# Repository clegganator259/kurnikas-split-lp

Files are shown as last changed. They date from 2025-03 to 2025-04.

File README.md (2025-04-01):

# kurnikas-split-lp
My attempt at designing my perfect split ergo keyboard

# Attribution

For the battery connector and led footprints @celolides fantastic [footprint library](https://github.com/ceoloide/ergogen-footprints)
For the choc v1 reversible footprints @ergogen + @infused-kim, @ceoloide, @grazfather, @nxtk improvements

For the videos that helped make this possible [Christian Sellig's wonderful video](https://www.youtube.com/watch?v=7UXsD7nSfDY)
# BOM
## PCB Components
|Component | Quantity|
|---|---:|
|kurnikas-split-lp PCB | 2|
|Nice nano v2 compatible board | 2|
|Choc v1 Key switches | 64|
|SK6812 mini-e RGB | 64|
|EC12/EC11 low profile encoder | 2|
|1N4148W SOD123 Diodes | 64/66 if using EC11 Encoder|
|JST PH2 board connector | 2|
|3.7v Lipo battery thickness < 8mm | 2|
|JST PH2 male connectors for batteries| 2|
|7 pin on/off toggle slide switch | 2|
|SKQGABE010 touch switch smd | 2|

## Case components
### Full case
|Component | Quantity|
|---|---:|
|8mm m2 standoffs  | 10|
|m2 flat top screws| 10|
|[Left hand faceplate](production/full-case-3dprint/face-plate-left.stl)| 1|
|[Right hand faceplate](production/full-case-3dprint/face-plate-right.stl)| 1|
|[Left hand Backplate](production/full-case-3dprint/base-plate-right.stl)| 1|
|[Right hand Backplate](production/full-case-3dprint/base-plate-left.stl)| 1|

### Sandwich Case
|Component | Quantity|
|---|---:|
|m2x4mm chicago screws with max 3mm OD | 10|
|Faceplate ([laser cut](production/sandwich-case-laser-cut/faceplate.dxf)/[3d printed](production/sandwich-case-3dprint/faceplate.stl)) |2|
|Baseplate ([laser cut](production/sandwich-case-laser-cut/baseplate.dxf)/[3d printed](production/sandwich-case-3dprint/baseplate.stl)) |2|

## Making your own

For a more detailed tutorial please go to [the build tutorial](docs/tutorial.md)

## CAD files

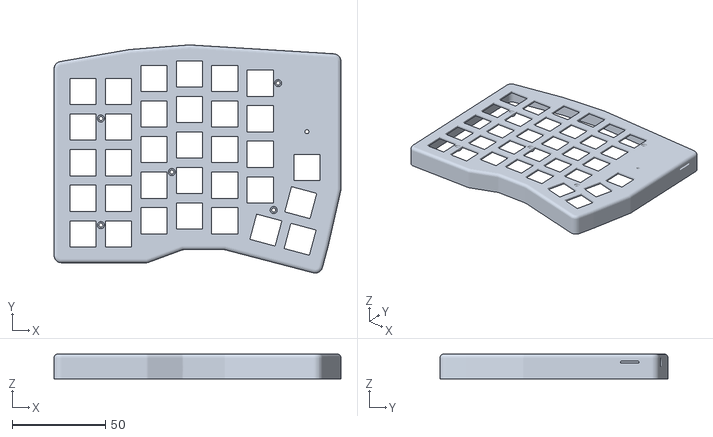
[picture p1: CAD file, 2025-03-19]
production/full-case-3dprint/face-plate-left.stl
153.8 x 122.3 x 13.3

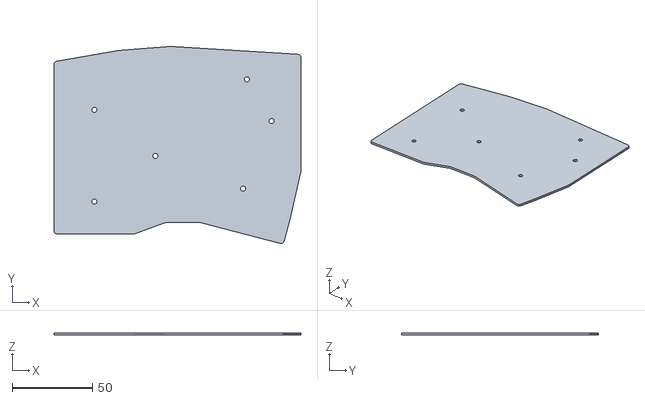
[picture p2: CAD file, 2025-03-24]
production/sandwich-case-3dprint/baseplate.stl
153.8 x 122.7 x 1.50

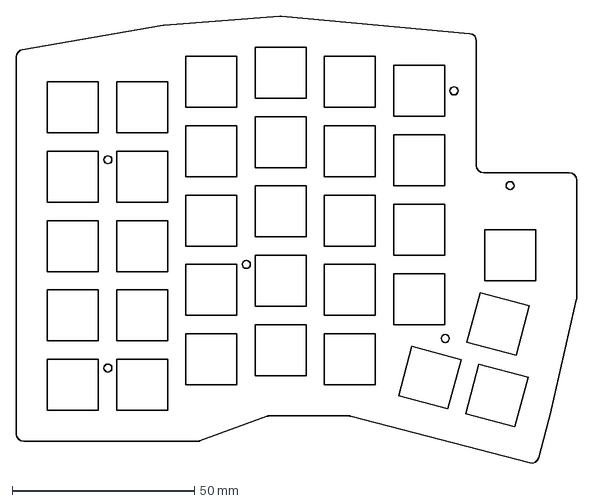
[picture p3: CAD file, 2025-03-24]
production/sandwich-case-laser-cut/faceplate.dxf
153.8 x 122.9 mm

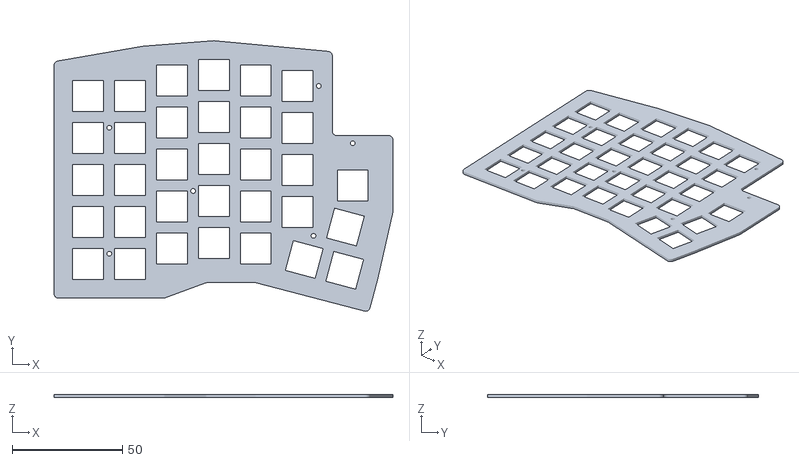
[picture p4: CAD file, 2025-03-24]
production/sandwich-case-3dprint/faceplate.stl
153.8 x 122.7 x 1.50

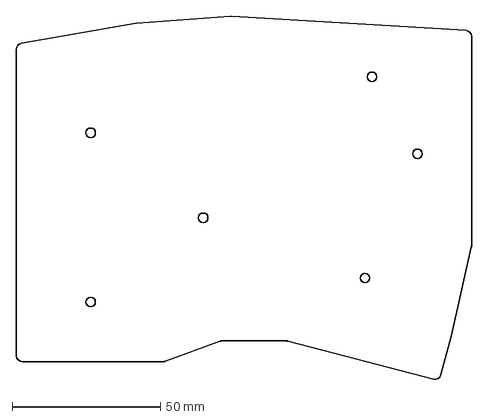
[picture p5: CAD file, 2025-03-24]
production/sandwich-case-laser-cut/baseplate.dxf
153.8 x 122.9 mm

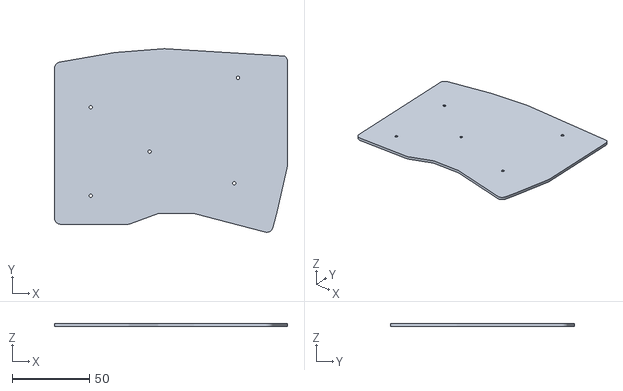
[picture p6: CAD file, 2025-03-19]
production/full-case-3dprint/base-plate-left.stl
150.3 x 118.5 x 2.00

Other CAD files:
production/full-case-3dprint/face-plate-right.stl
production/full-case-3dprint/base-plate-right.stl

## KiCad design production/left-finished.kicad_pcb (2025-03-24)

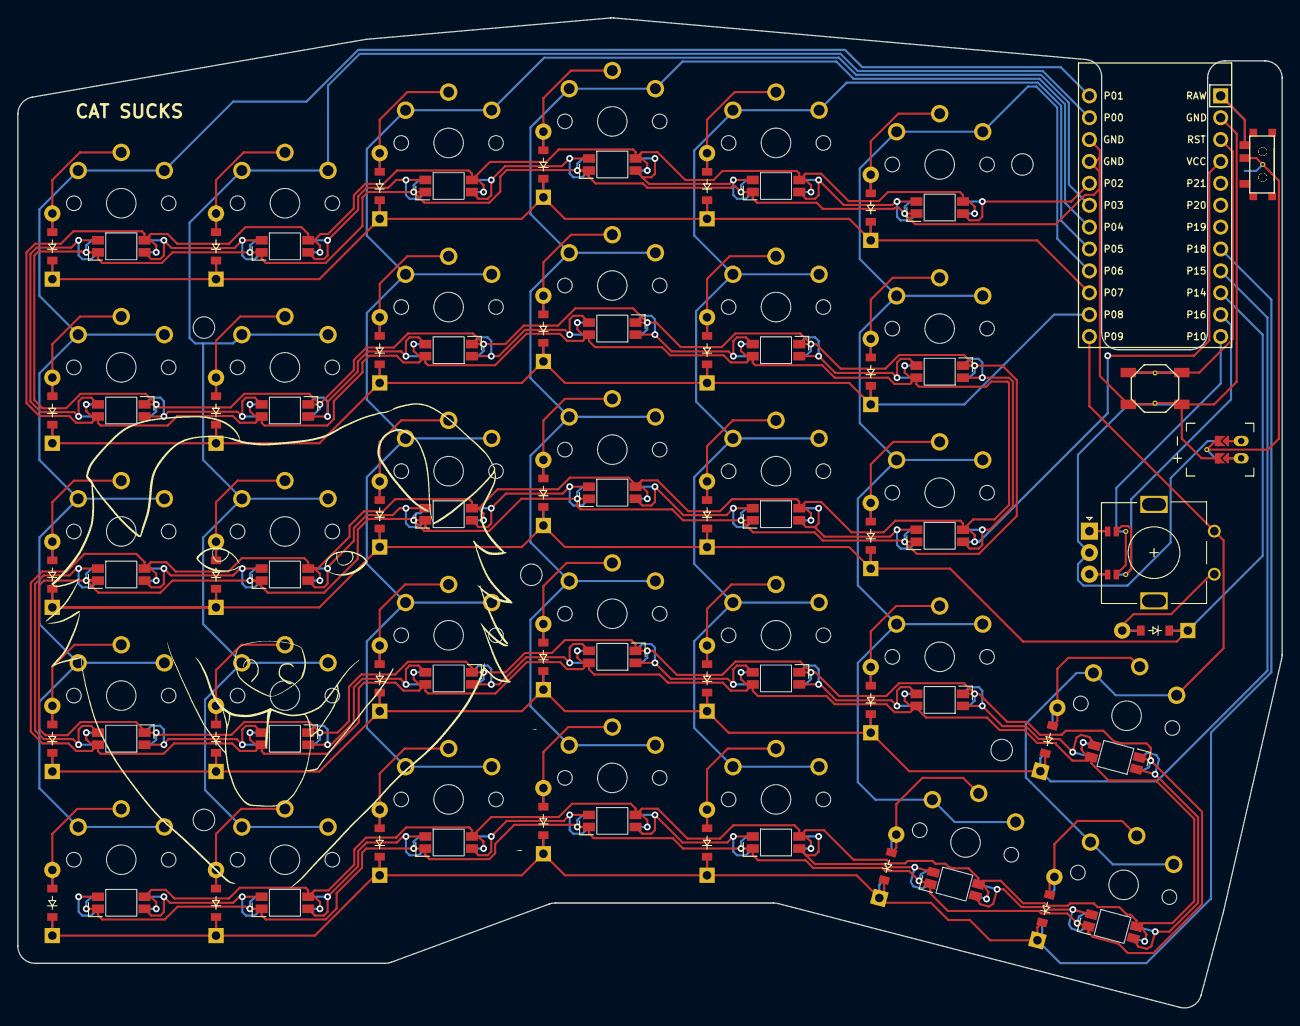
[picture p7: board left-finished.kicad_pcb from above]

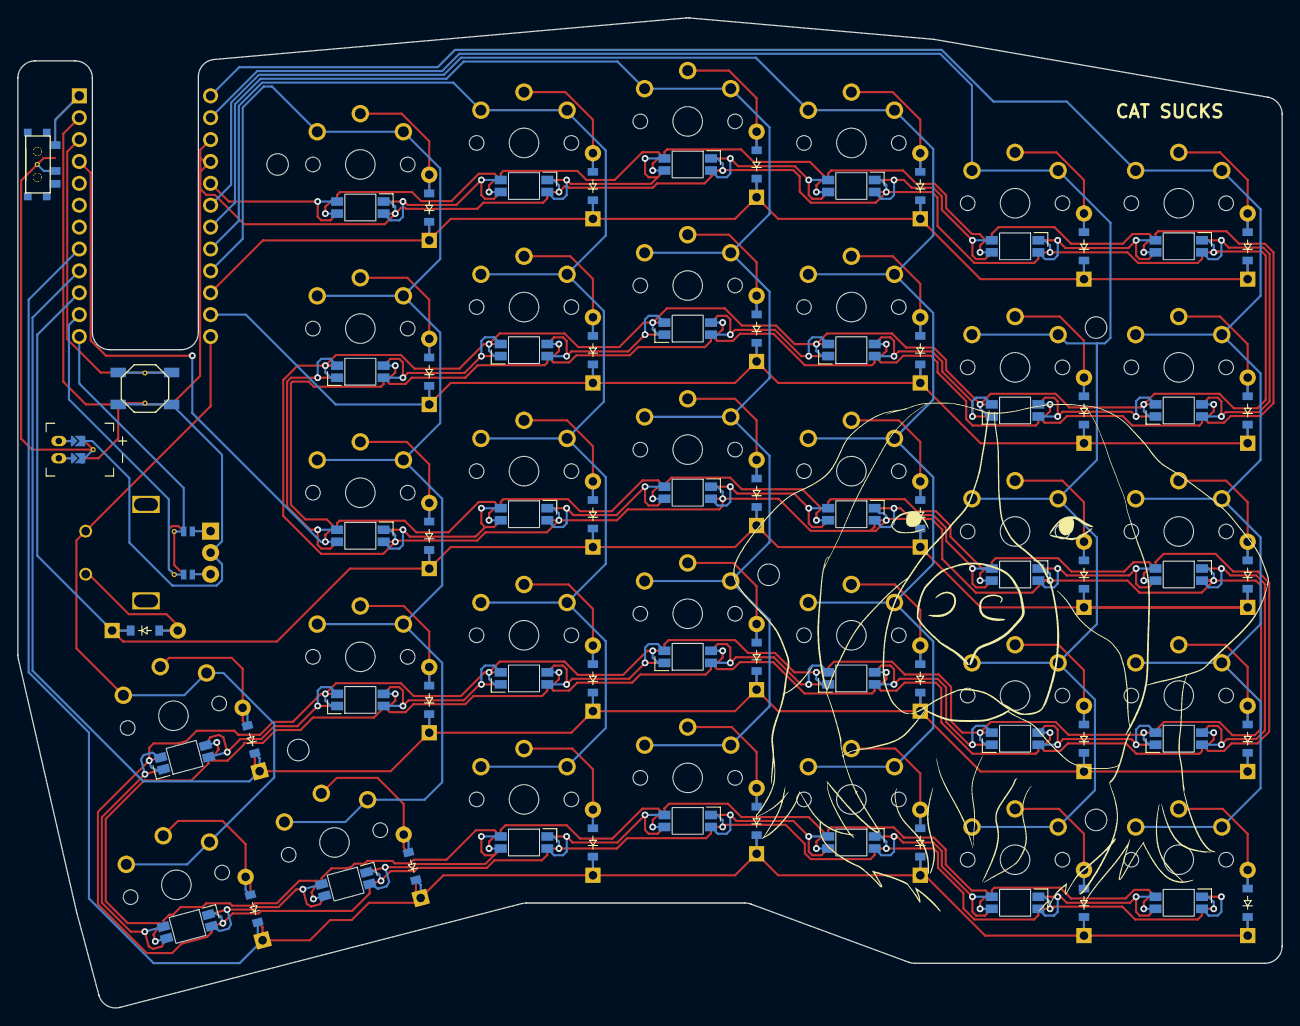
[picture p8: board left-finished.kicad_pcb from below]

Board: 2 copper layers, 146.8 x 114.9 mm, 108 parts (32 on the bottom side), 88 nets.

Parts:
B1, B2: SW_TACT_ALPS_SKQGABE010
D1, D2, D3, D4, D5, D6, D7, D8, D9, D10, D11, D12, D13, D14, D15, D16, D17, D18, D19, D20, D21, D22, D23, D24, D25, D26, D27, D28, D29, D30, D31, D32, D33: ComboDiode
J1, J2, J3, J4: Jumper
JST1: battery_connector_jst_ph_2
LED1, LED2, LED3, LED4, LED5, LED6, LED7, LED8, LED9, LED10, LED11, LED12, LED13, LED14, LED15, LED16, LED17, LED18, LED19, LED20, LED21, LED22, LED23, LED24, LED25, LED26, LED27, LED28, LED29, LED30, LED31, LED32: led_SK6812mini-e (per-key, reversible)
MCU1: ProMicro
ROT1: rotary_encoder
S1, S2, S3, S4, S5, S6, S7, S8, S9, S10, S11, S12, S13, S14, S15, S16, S17, S18, S19, S20, S21, S22, S23, S24, S25, S26, S27, S28, S29, S30, S31, S32: PG1350
T1, T2: SPDT_C128955

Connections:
GND: B1.1, B2.1, JST1.2, LED1.3, LED2.3, LED3.3, LED4.3, LED5.3, LED6.3, LED7.3, LED8.3, LED9.3, LED10.3, LED11.3, LED12.3, LED13.3, LED14.3, LED15.3, LED16.3, LED17.3, LED18.3, LED19.3, LED20.3, LED21.3, LED22.3, LED23.3, LED24.3, LED25.3, LED26.3, LED27.3, LED28.3, LED29.3, LED30.3, LED31.3, LED32.3, MCU1.2, MCU1.15, MCU1.16, ROT1.C
JST1_1: JST1.11, JST1.21, JST1.31
JST1_2: JST1.12, JST1.22, JST1.32
P0: MCU1.14, S6.1, S7.1, S8.1, S9.1, S10.1
P1: MCU1.13, S1.1, S2.1, S3.1, S4.1, S5.1
P2: LED17.2, MCU1.17
P3: MCU1.18, S11.1, S12.1, S13.1, S14.1, S15.1
P4: MCU1.19, S16.1, S17.1, S18.1, S19.1, S20.1
P5: MCU1.20, S21.1, S22.1, S23.1, S24.1, S25.1
P6: MCU1.21, S26.1, S27.1, S28.1, S29.1, S30.1
P7: D5.1, D10.1, D15.1, D20.1, D25.1, D29.1, MCU1.22
P8: D4.1, D9.1, D14.1, D19.1, D24.1, D28.1, MCU1.23
P9: MCU1.24, ROT1.1, S31.1, S32.1
P10: J2.1, J3.1, MCU1.12
P14: D3.1, D8.1, D13.1, D18.1, D23.1, D27.1, D33.1, MCU1.10
P15: D2.1, D7.1, D12.1, D17.1, D22.1, D26.1, D32.1, MCU1.9
P16: J1.1, J4.1, MCU1.11
P18: D1.1, D6.1, D11.1, D16.1, D21.1, D30.1, D31.1, MCU1.8
RAW: MCU1.1, T1.3, T2.1
RB_ROW: D33.2, ROT1.2
RST: B1.2, B2.2, MCU1.3
VCC: LED1.1, LED2.1, LED3.1, LED4.1, LED5.1, LED6.1, LED7.1, LED8.1, LED9.1, LED10.1, LED11.1, LED12.1, LED13.1, LED14.1, LED15.1, LED16.1, LED17.1, LED18.1, LED19.1, LED20.1, LED21.1, LED22.1, LED23.1, LED24.1, LED25.1, LED26.1, LED27.1, LED28.1, LED29.1, LED30.1, LED31.1, LED32.1, MCU1.4
index_bottom: D22.2, S22.2
index_home: D23.2, S23.2
index_mod: D21.2, S21.2
index_num: D25.2, S25.2
index_top: D24.2, S24.2
inner_bottom: D26.2, S26.2
inner_bottom_thumbs: D31.2, S31.2
inner_home: D27.2, S27.2
inner_num: D29.2, S29.2
inner_top: D28.2, S28.2
inner_top_thumbs: D32.2, S32.2
led_1: LED15.2, LED17.4
led_2: LED12.2, LED15.4
led_3: LED9.2, LED12.4
led_4: LED6.2, LED9.4
led_5: LED3.2, LED6.4
led_6: LED3.4, LED21.2
led_7: LED21.4, LED23.2
led_8: LED23.4, LED25.2
led_9: LED25.4, LED27.2
led_10: LED27.4, LED29.2
led_11: LED29.4, LED31.2
led_12: LED16.2, LED31.4
led_13: LED14.2, LED16.4
led_14: LED11.2, LED14.4
led_15: LED8.2, LED11.4
led_16: LED5.2, LED8.4
led_17: LED2.2, LED5.4
led_18: LED2.4, LED20.2
led_19: LED20.4, LED22.2
led_20: LED22.4, LED24.2
led_21: LED24.4, LED26.2
led_22: LED26.4, LED28.2
led_23: LED28.4, LED30.2
led_24: LED30.4, LED32.2
led_25: LED19.2, LED32.4
led_26: LED18.2, LED19.4
led_27: LED13.2, LED18.4
led_28: LED10.2, LED13.4
led_29: LED7.2, LED10.4
led_30: LED4.2, LED7.4
led_31: LED1.2, LED4.4
middle_bottom: D17.2, S17.2
middle_home: D18.2, S18.2
middle_mod: D16.2, S16.2
middle_num: D20.2, S20.2
middle_top: D19.2, S19.2
outer_bottom: D2.2, S2.2
outer_bottom_thumbs: D30.2, S30.2
outer_home: D3.2, S3.2
outer_mod: D1.2, S1.2
outer_num: D5.2, S5.2
outer_top: D4.2, S4.2
pinky_bottom: D7.2, S7.2
pinky_home: D8.2, S8.2
pinky_mod: D6.2, S6.2
pinky_num: D10.2, S10.2
pinky_top: D9.2, S9.2
pos: JST1.1, T1.2, T2.2
ring_bottom: D12.2, S12.2
ring_home: D13.2, S13.2
ring_mod: D11.2, S11.2
ring_num: D15.2, S15.2
ring_top: D14.2, S14.2
scroll-j1: J1.2, J3.2, ROT1.A
scroll-j2: J2.2, J4.2, ROT1.B

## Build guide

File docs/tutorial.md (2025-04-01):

# Tutorial

## Planning your build - what decisions you need to make
This build has several options that are available as you build this keyboard depending on your requirements for durabillity, battery life and aesthetics.

### Which case?
There are two case options, the full case and the sandwich case. The full case is a taller, however it has space for a larger battery, and the full pcb is enclosed.

The sandwich case is lower profile and lighter, however it is less durable, the pro micro is exposed and the sides are open to any water ingress. It can also only take a battery that is small enoguh to fit under the promicro.

### Which encoder?
There are two options for the rotary encoder, the ec11 or ec12. The ec11 has a push button, however ec11s tend to be higher profiler than the lowest profile ec12 encoders. ec12 encoders are identical but don't have the push button.
### LEDs?
This keyboard supports RGB background LEDs, however they have a huge impact on battery life. I would not advise using LEDs unless you are going for the full case with a large battery.
### Didodes

This pcb supports both through hole and surface mount diodes

### Battery choice
If you are choosing the sandwich case this must be one of the small 3.7v 110mah batteries that can fit under the pro micro.

For the full case, your main constraint is thickness, anything 5mm or under should fit, this includes old phone batteries if you wish to recycle.

I would advise choosing a capacity 500mah or greater so you can take advantage of the nice-nano's faster charging capabillity (500ma vs 100ma)

### Switches/Keycaps

The fun bit! Here you can choose any choc v1 low profile switches with matching keycaps.

## Ordering/printing the parts
### PCB

To get the PCB made, you can use the [zip file](production/PCBGerberFiles.zip) and send it to a PCB maker, you will need at least 2 copies of the PCB, but that won't be an issue as most fabs have a minimum order quantity of 5

### Sandwich case
You will need to print 2 copies of each file

### Full case
You will need to print 1 copy of each file

## Starting construction

I will give examples based on one side of the PCB but my advice would be to do each of these steps with both pcbs laid out side by side. The one exception for this will be in adding the pro-micros, as the right hand side will have to be installed upside down.

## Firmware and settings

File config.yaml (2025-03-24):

meta:
  engine: 4.1.0 # Min Ergogen version for KiCad 8 footprints
units:
  kx: u
  ky: U
  px: u+5
  py: U+5
  nnx: 18.5
  nny: 33
  casepadding: 3.5
  holeradius: 1.1

points:
  zones:
    matrix:
      key:
        padding: 1ky
        spread: 1kx

      columns:
        outer:
          key.column_net: P1
          key.column_index: 0
          rows:
            mod.key.this_led: led_31
            mod.key.next_led: led_32
            bottom.key.this_led: led_18
            bottom.key.next_led: led_19
            home.key.this_led: led_17
            home.key.next_led: led_18
            top.key.this_led: led_6
            top.key.next_led: led_7
            num.key.this_led: led_5
            num.key.next_led: led_6
        pinky:
          key.column_net: P0
          key.column_index: 1
          rows:
            mod.key.this_led: led_30
            mod.key.next_led: led_31
            bottom.key.this_led: led_19
            bottom.key.next_led: led_20
            home.key.this_led: led_16
            home.key.next_led: led_17
            top.key.this_led: led_7
            top.key.next_led: led_8
            num.key.this_led: led_4
            num.key.next_led: led_5
        ring:
          key.column_net: P3
          key.column_index: 2
          rows:
            mod.key.this_led: led_29
            mod.key.next_led: led_30
            bottom.key.this_led: led_20
            bottom.key.next_led: led_21
            home.key.this_led: led_15
            home.key.next_led: led_16
            top.key.this_led: led_8
            top.key.next_led: led_9
            num.key.this_led: led_3
            num.key.next_led: led_4
          key.stagger: 7
        middle:
          key.column_net: P4
          key.column_index: 3
          key.stagger: 2.5
          rows:
            mod.key.this_led: led_28
            mod.key.next_led: led_29
            bottom.key.this_led: led_21
            bottom.key.next_led: led_22
            home.key.this_led: led_14
            home.key.next_led: led_15
            top.key.this_led: led_9
            top.key.next_led: led_10
            num.key.this_led: led_2
            num.key.next_led: led_3
        index:
          key.column_net: P5
          key.column_index: 4
          key.stagger: -2.5
          rows:
            mod.key.this_led: led_27
            mod.key.next_led: led_28
            bottom.key.this_led: led_22
            bottom.key.next_led: led_23
            home.key.this_led: led_13
            home.key.next_led: led_14
            top.key.this_led: led_10
            top.key.next_led: led_11
            num.key.this_led: led_1
            num.key.next_led: led_2
        inner:
          key:
            stagger: -2.5
            column_net: P6
          rows:
            bottom.key.this_led: led_23
            bottom.key.next_led: led_24
            home.key.this_led: led_12
            home.key.next_led: led_13
            top.key.this_led: led_11
            top.key.next_led: led_12
            num.key.this_led: P2
            num.key.next_led: led_1
            mod:
              skip: true

      anchor:
        shift: [100, -150]
      rows:
        mod:
          row_index: 28 
          row_net: P18
        bottom:
          row_net: P15
          row_index: 21 
        home:
          row_net: P14
          row_index: 14
        top:
          row_net: P8
          row_index: 7
        num:
          row_net: P7
          row_index: 0
    thumbs:
      key:
        padding: 1ky
        spread: 1kx
      columns:
        outer:
          key:
            column_net: P6
            splay: -15
            column_index: 5
          rows:
            top_thumbs.skip: true
            bottom_thumbs.key.this_led: led_26
            bottom_thumbs.key.next_led: led_27
        inner:
          key.column_index: 6
          key.column_net: P9
          rows:
            top_thumbs.key.this_led: led_24
            top_thumbs.key.next_led: led_25
            bottom_thumbs.key.this_led: led_25
            bottom_thumbs.key.next_led: led_26
      rows:
        bottom_thumbs:
          row_net: P18
        top_thumbs:
          row_net: P15
          shift: [-0.25kx, 0]
      anchor:
        ref: matrix_inner_mod
        shift: [3, -2.5]
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

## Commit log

2025-03-19 Feat: Adding production files
    [Base Plate Left v3.stl, Base Plate Right v3.stl, Face Plate Left v9.stl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]
2025-03-19 Docs: Add bom
2025-03-24 Production ready
    [Base Plate Left v3.stl, Base Plate Right v3.stl, Face Plate Full Left v9.stl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]
2025-03-26 Chore: Rename files for more consistent naming
    [base-plate-left.stl, base-plate-right.stl, baseplate.dxf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]
